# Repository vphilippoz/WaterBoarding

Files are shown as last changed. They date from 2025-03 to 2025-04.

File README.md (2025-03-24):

# WaterBoarding

This project is under developpment.

When uploaded to an ESP32, this code allows any user to toggle a water pump from a web interface. The ESP32 hosts a web page such that any device on the same network can interract with it.

## Requirements

### Arduino IDE

1. Install the esp32 board support by Espressif Systems
1. Select Tools > USB CDC On Boot > Enabled from the Arduino IDE menus (required to make Serial.print work on ESP32 boards)

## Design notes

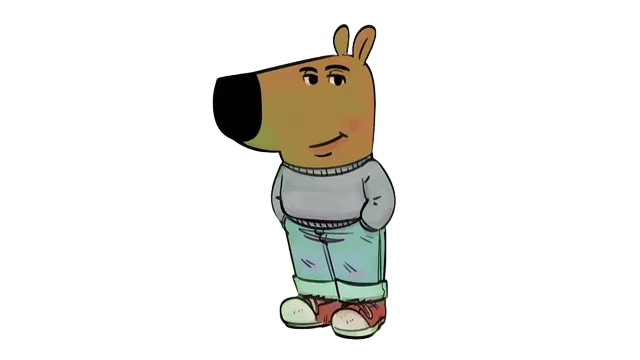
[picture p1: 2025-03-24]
PCB/chill-guy-meme-transparent.png

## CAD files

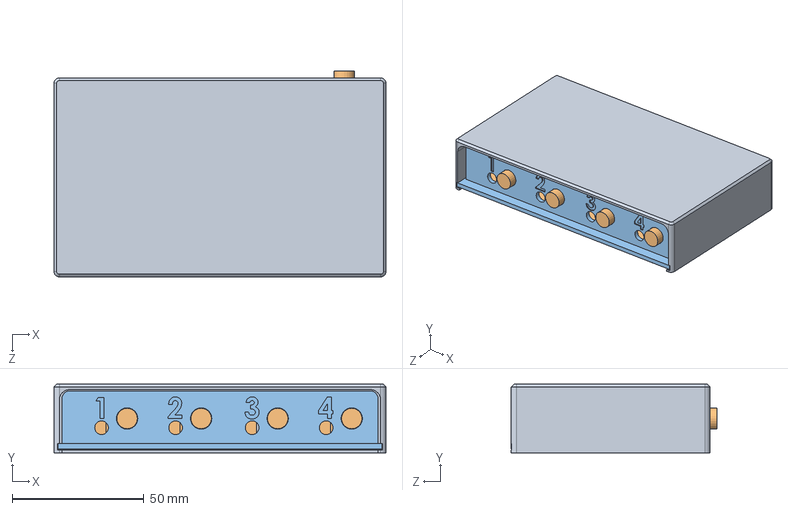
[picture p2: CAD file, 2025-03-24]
3D/asm.SLDASM
126.0 x 26.0 x 78.1 mm
pcb
bas
haut

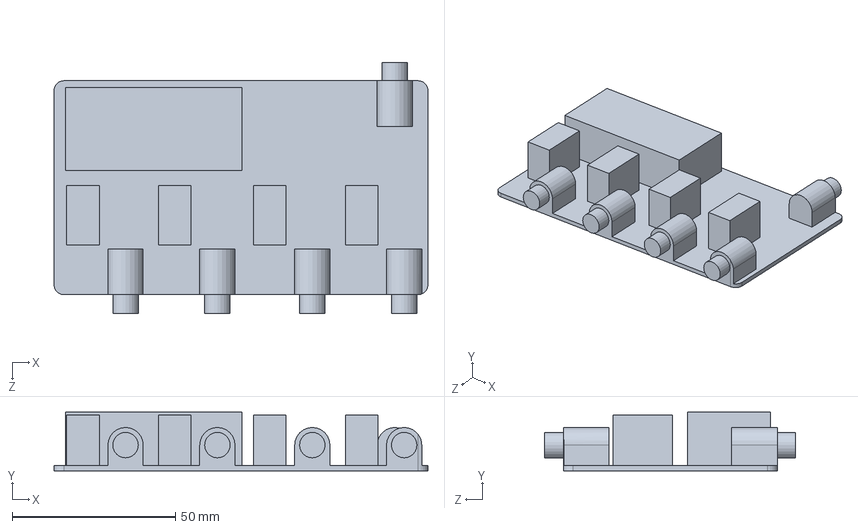
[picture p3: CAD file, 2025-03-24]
3D/pcb.SLDPRT
114.4 x 18.0 x 76.8 mm

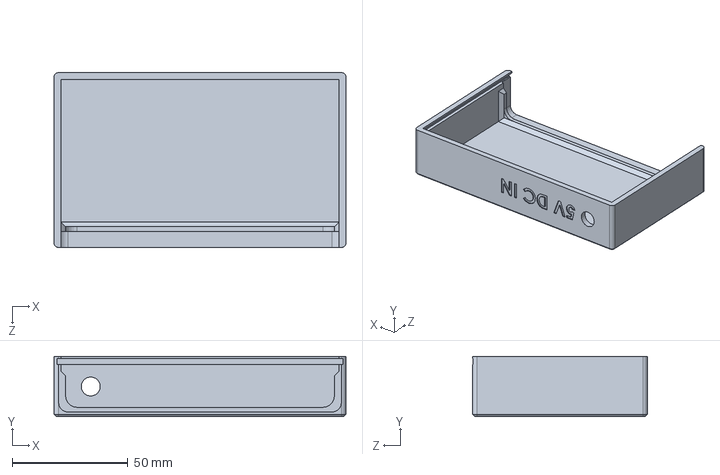
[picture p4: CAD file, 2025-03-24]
3D/haut.SLDPRT
126.0 x 26.0 x 75.5 mm

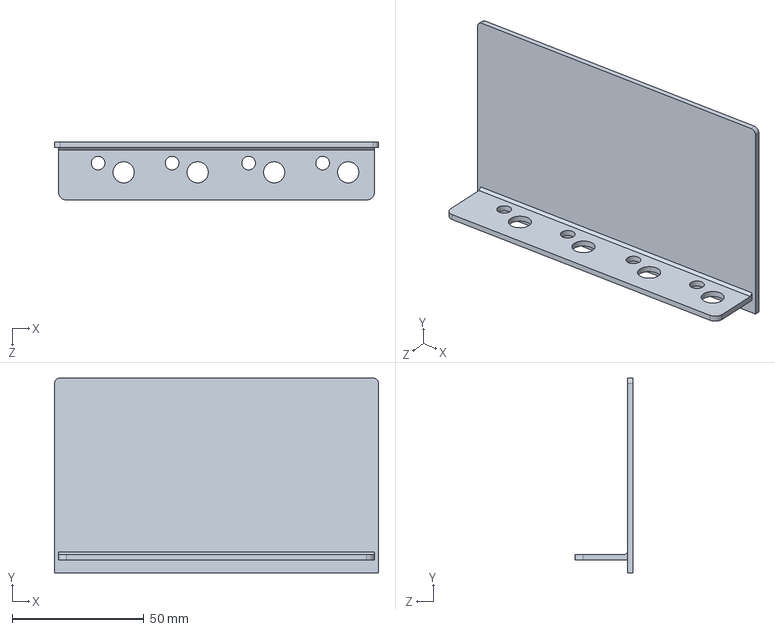
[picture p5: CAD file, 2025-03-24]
3D/bas.SLDPRT
123.0 x 74.0 x 22.0 mm

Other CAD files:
3D/bas.3MF
3D/haut.3MF

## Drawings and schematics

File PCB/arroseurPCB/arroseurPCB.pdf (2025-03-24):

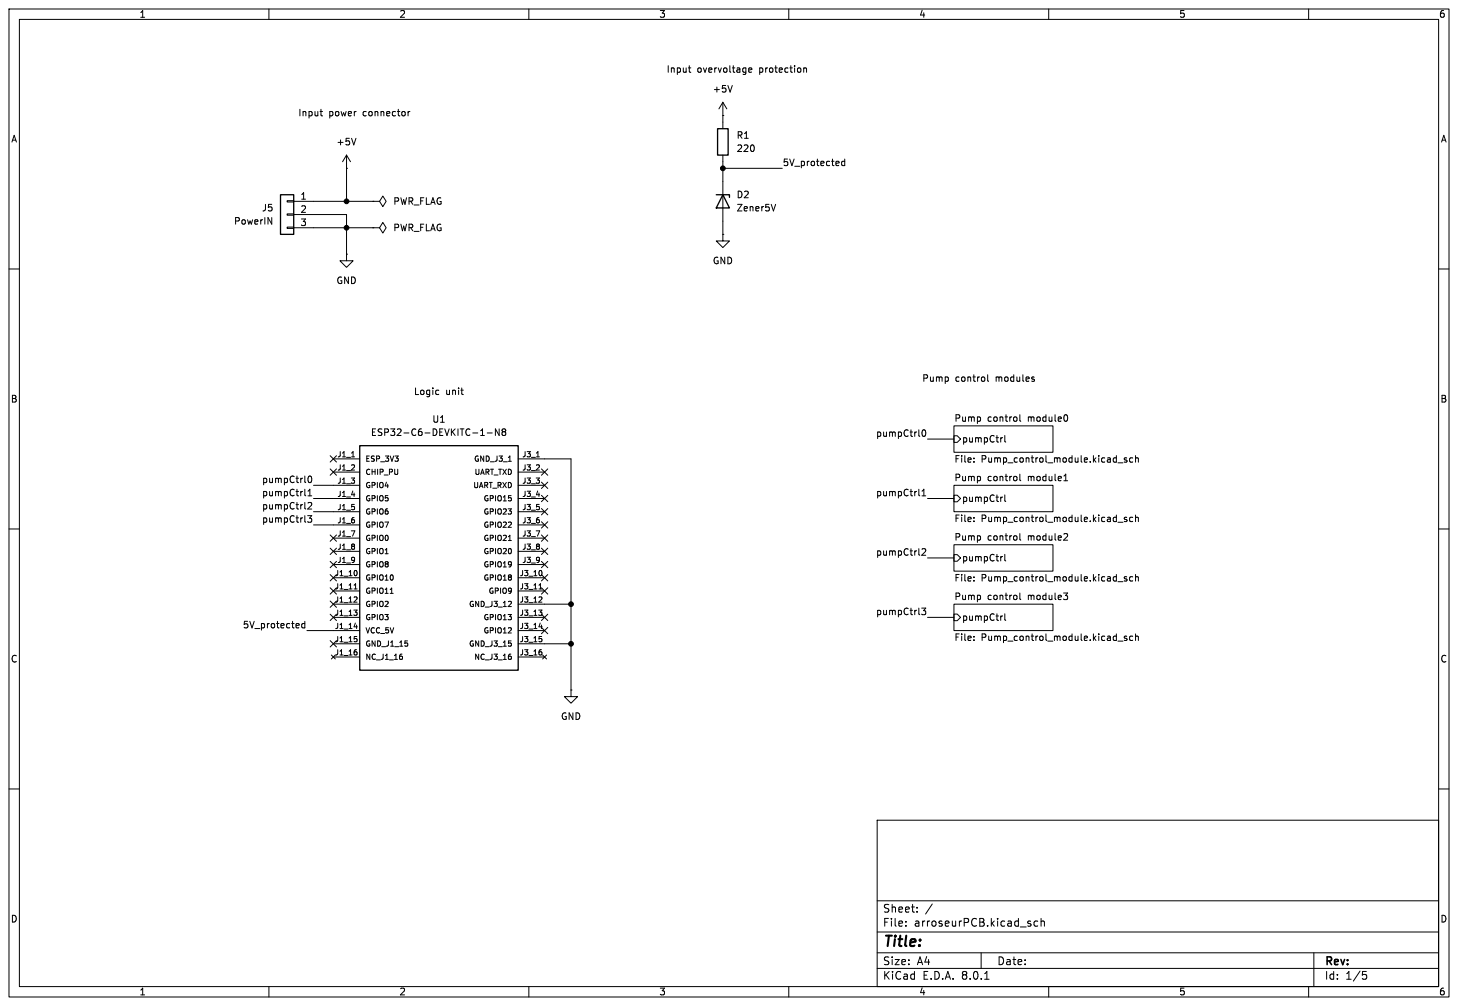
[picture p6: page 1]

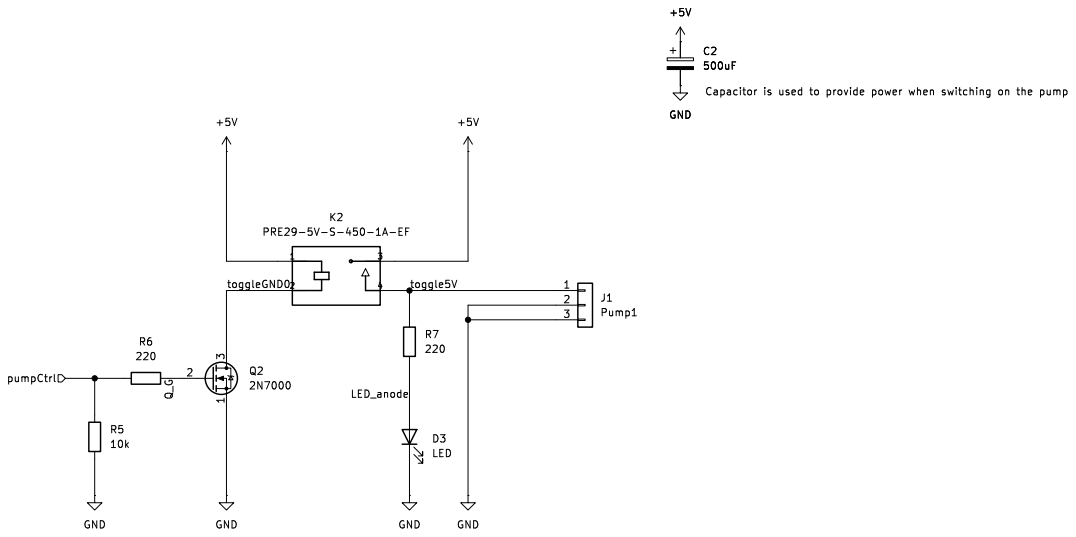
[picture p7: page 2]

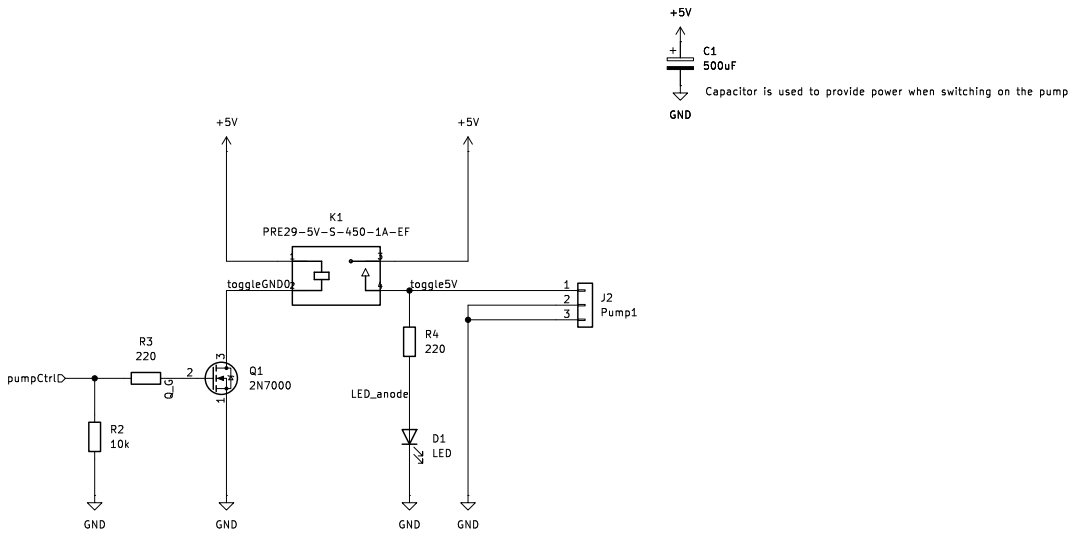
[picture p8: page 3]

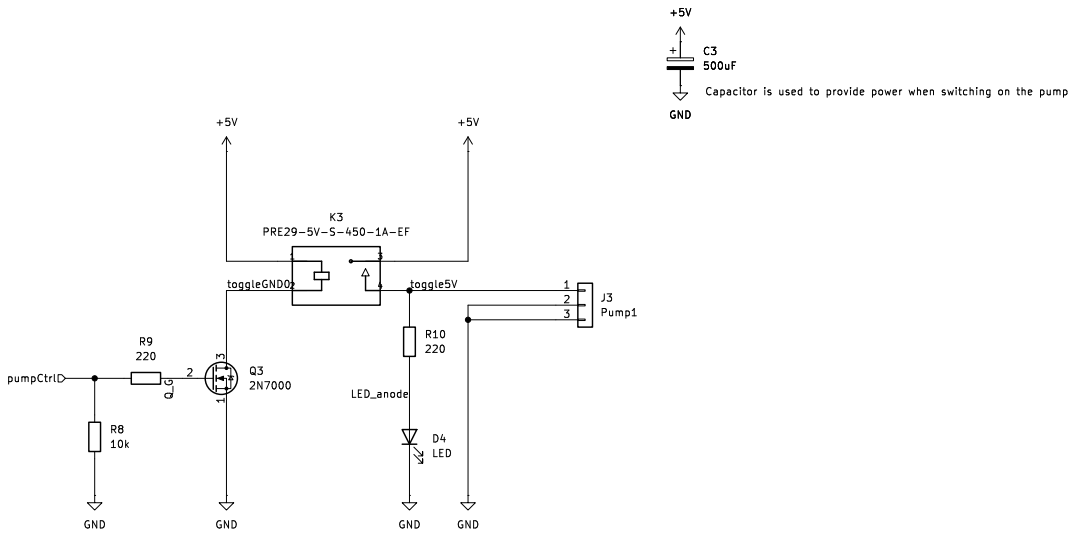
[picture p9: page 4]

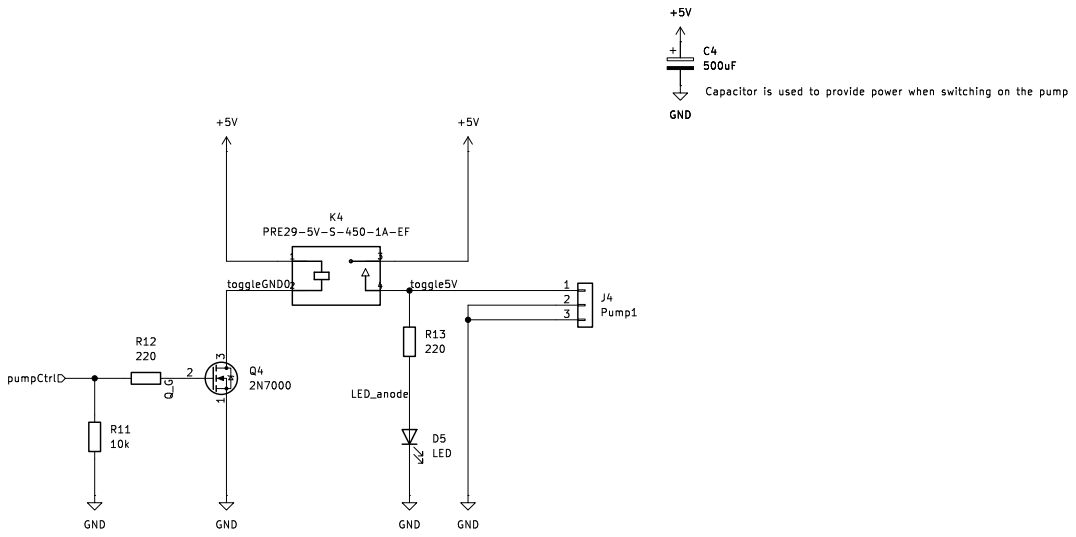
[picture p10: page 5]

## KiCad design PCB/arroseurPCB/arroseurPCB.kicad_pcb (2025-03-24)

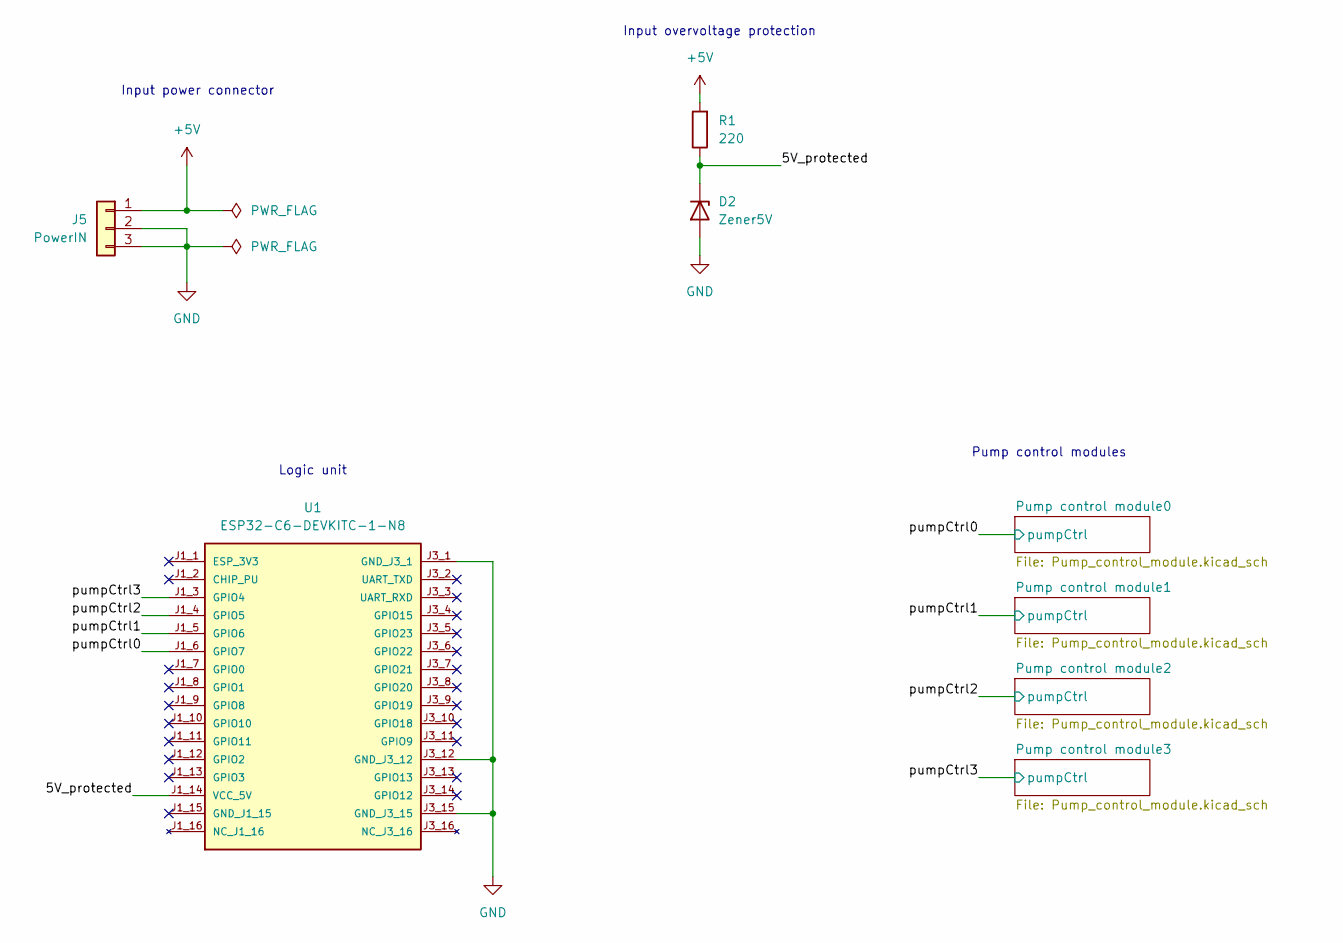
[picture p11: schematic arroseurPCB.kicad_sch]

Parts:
D2: Zener5V; D_DO-41_SOD81_P7.62mm_Horizontal
J5: PowerIN; PJ-112AH
R1: 220; R_Axial_DIN0309_L9.0mm_D3.2mm_P15.24mm_Horizontal
U1: ESP32-C6-DEVKITC-1-N8; MODULE_ESP32-C6-DEVKITC-1-N8; PARTREV 1.3

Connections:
+5V: J5.1, R1.2; also elsewhere on the board
/5V_protected: D2.1 (K), R1.1, U1.J1_14 (VCC_5V)
/pumpCtrl0: U1.J1_6 (GPIO7); also elsewhere on the board
/pumpCtrl1: U1.J1_5 (GPIO6); also elsewhere on the board
/pumpCtrl2: U1.J1_4 (GPIO5); also elsewhere on the board
/pumpCtrl3: U1.J1_3 (GPIO4); also elsewhere on the board
GND: D2.2 (A), J5.2, J5.3, U1.J3_1 (GND_J3_1), U1.J3_12 (GND_J3_12), U1.J3_15 (GND_J3_15); also elsewhere on the board

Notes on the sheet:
Logic unit
Input power connector
Input overvoltage protection
Pump control modules

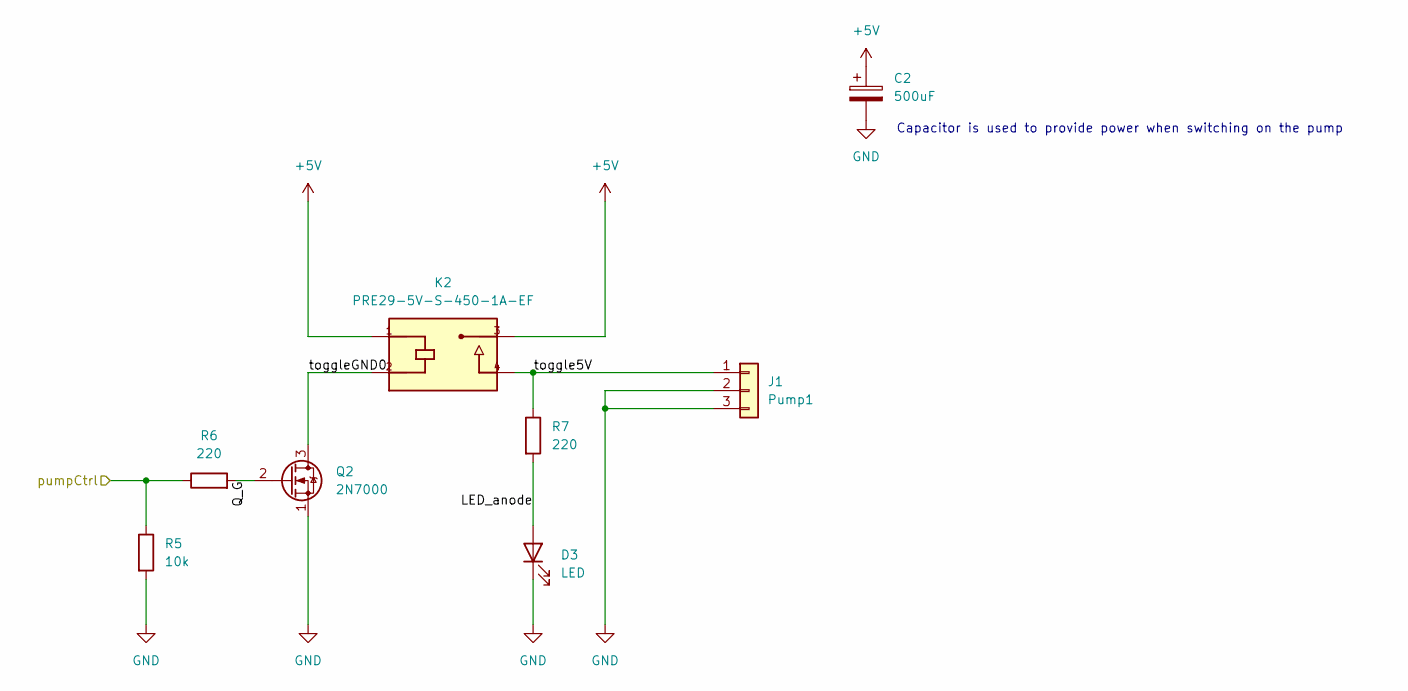
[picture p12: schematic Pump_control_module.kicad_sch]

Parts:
C2: 500uF; CP_Radial_D6.3mm_P2.50mm
D3: LED; LED_D5.0mm
J1: Pump1; PJ-112AH
K2: PRE29-5V-S-450-1A-EF; RELAY_PRE29-5V-S-450-1A-EF
Q2: 2N7000; TO-92L_HandSolder
R5: 10k; R_Axial_DIN0309_L9.0mm_D3.2mm_P15.24mm_Horizontal
R6, R7: 220; R_Axial_DIN0309_L9.0mm_D3.2mm_P15.24mm_Horizontal

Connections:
+5V: C2.1, K2.1, K2.3; also elsewhere on the board
/Pump control module0/LED_anode: D3.2 (A), R7.2
/Pump control module0/Q_G: Q2.2 (G), R6.2
/Pump control module0/toggle5V: J1.1, K2.4, R7.1
/Pump control module0/toggleGND0: K2.2, Q2.3 (D)
/pumpCtrl0: R5.1, R6.1; also elsewhere on the board
GND: C2.2, D3.1 (K), J1.2, J1.3, Q2.1 (S), R5.2; also elsewhere on the board

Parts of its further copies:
C1, C3, C4: 500uF; CP_Radial_D6.3mm_P2.50mm
D1, D4, D5: LED; LED_D5.0mm
J2: Pump1; PJ-112AH
K1, K3, K4: PRE29-5V-S-450-1A-EF; RELAY_PRE29-5V-S-450-1A-EF
Q1, Q3, Q4: 2N7000; TO-92L_HandSolder
R2, R8, R11: 10k; R_Axial_DIN0309_L9.0mm_D3.2mm_P15.24mm_Horizontal
R3, R4, R9, R10, R12, R13: 220; R_Axial_DIN0309_L9.0mm_D3.2mm_P15.24mm_Horizontal

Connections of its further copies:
+5V: C1.1, C3.1, C4.1, K1.1, K1.3, K3.1, K3.3, K4.1, K4.3; also elsewhere on the board
/Pump control module1/LED_anode: D1.2 (A), R4.2
/Pump control module1/Q_G: Q1.2 (G), R3.2
/Pump control module1/toggle5V: J2.1, K1.4, R4.1
/Pump control module1/toggleGND0: K1.2, Q1.3 (D)
/Pump control module2/LED_anode: D4.2 (A), R10.2
/Pump control module2/Q_G: Q3.2 (G), R9.2
/Pump control module2/toggle5V: K3.4, R10.1; also elsewhere on the board
/Pump control module2/toggleGND0: K3.2, Q3.3 (D)
/Pump control module3/LED_anode: D5.2 (A), R13.2
/Pump control module3/Q_G: Q4.2 (G), R12.2
/Pump control module3/toggle5V: K4.4, R13.1; also elsewhere on the board
/Pump control module3/toggleGND0: K4.2, Q4.3 (D)
/pumpCtrl1: R2.1, R3.1; also elsewhere on the board
/pumpCtrl2: R8.1, R9.1; also elsewhere on the board
/pumpCtrl3: R11.1, R12.1; also elsewhere on the board
GND: C1.2, C3.2, C4.2, D1.1 (K), D4.1 (K), D5.1 (K), J2.2, J2.3, Q1.1 (S), Q3.1 (S), Q4.1 (S), R2.2, R8.2, R11.2; also elsewhere on the board

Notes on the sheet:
Capacitor is used to provide power when switching on the pump

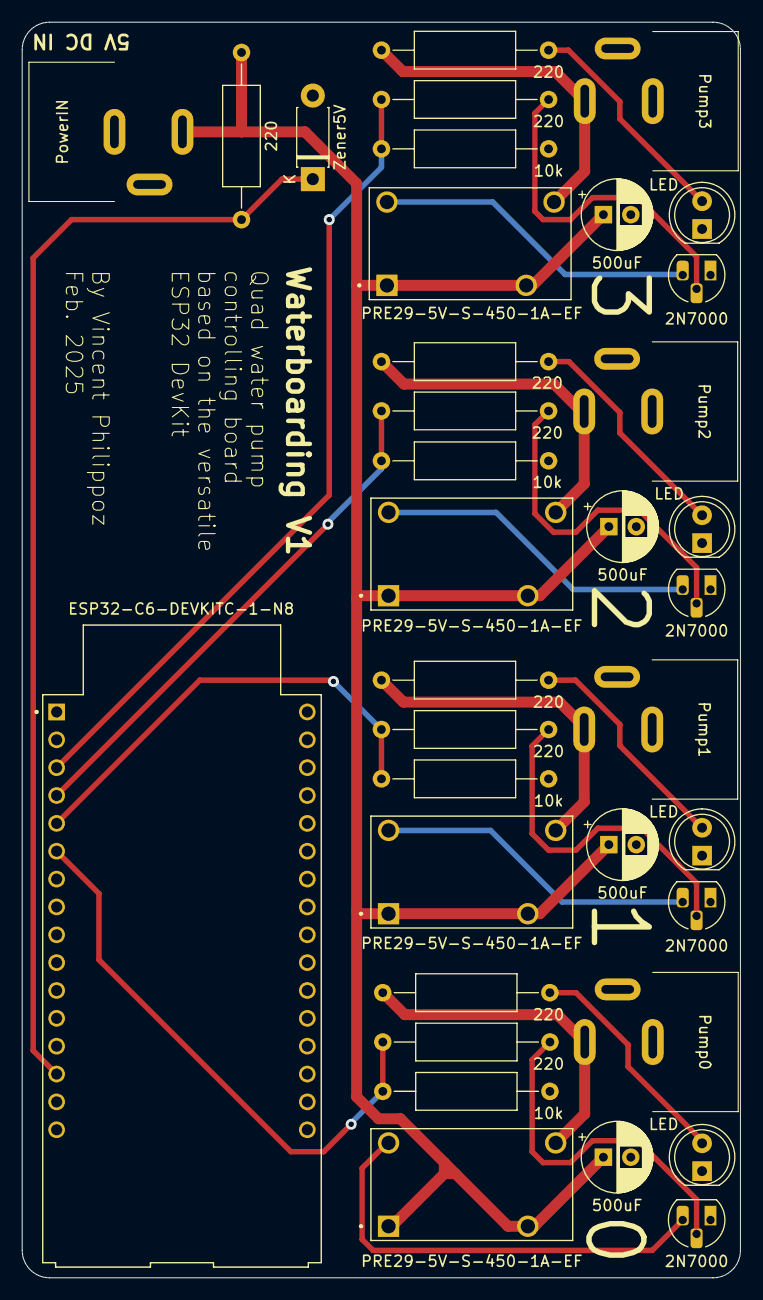
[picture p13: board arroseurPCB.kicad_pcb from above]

Board: 2 copper layers, 65.5 x 114.5 mm, 36 parts (0 on the bottom side), 23 nets.

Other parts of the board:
J3: Pump2; PJ-112AH
J4: Pump3; PJ-112AH

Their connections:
/Pump control module2/toggle5V: J3.1; also elsewhere on the board
/Pump control module3/toggle5V: J4.1; also elsewhere on the board
GND: J3.2, J3.3, J4.2, J4.3; also elsewhere on the board

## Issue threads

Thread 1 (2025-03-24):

Create clean framework

vphilippoz, 2025-03-24:
# Problem

The current codebase is a single .ino file without clear structure. Backend and frontend are mixed.

# Solution

A modular approach must be applied. Backend and frontend should be separated in different source files for greater flexibility and readability.

vphilippoz, 2025-03-27:
Resolved at commit 8648e07

Closed 2025-03-27.

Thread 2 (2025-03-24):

Onboard RGB LED as debugger

vphilippoz, 2025-03-24:
# Problem

When testing the code on the ESP32, one must either use a multimeter or serial communication to know what happens. This prevents easy testing and is not cool.

# Solution

Create a basic function that associates a color to each toggled GPIO. Thus, one can simply look at the board to see if and which GPIO is toggled.

vphilippoz, 2025-03-28:
Partially solved at release v1.0 but only one color is visible, so if two GPIOs are toggled only the last one is visible.

vphilippoz, 2025-03-28:
Issue solved by PR #5

Closed 2025-03-28.

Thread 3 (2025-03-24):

UI improvement

vphilippoz, 2025-03-24:
# Problem

The current web page is very basic and ugly.

# Solution

Make the web page more user friendly by using buttons, colors and text.

vphilippoz, 2025-04-07:
Solved with PR #6

Closed 2025-04-07.

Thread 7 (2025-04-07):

Water quantity control

vphilippoz, 2025-04-07:
# Problem

The current application only allows the user to toggle pumps. It is difficult to deliver a precise amount of water to a plant.

# Solution

Calibrate the water delivery (measure water flux) and adapt UI to deliver a requested quantity (for example, a slider with a "deliver now" button)

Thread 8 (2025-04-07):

Automated plan

vphilippoz, 2025-04-07:
# Problem

The watering system is not autonomous. A user is needed to toggle pumps.

# Solution

Create a watering schedule. At given times of the day, on given days of the week, the watering system activates autonomously. Schedule is either hardcoded (easy ugly) or setup on the web application (nice difficult).

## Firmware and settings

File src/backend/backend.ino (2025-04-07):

/*
Minimal version to test the backend library.

This code is a minimal version to test the backend library. It toggles the defined GPIOs and the corresponding LED color.
*/

#include "backend.hpp"

// Constants
constexpr unsigned int SERIAL_BAUD_RATE = 115200;
constexpr bool DEBUG = false;

void setup() {
    if(DEBUG) {
        // Open serial communications on the native USB port
        Serial.begin(SERIAL_BAUD_RATE);while(!Serial);
    }

    // Setup the library
    backend::setup(DEBUG);
    if(DEBUG) {Serial.println("Setup complete");}
}

void loop() {
    // // Toggle individually each pump
    // for(unsigned int i = 0; i < backend::NUM_PUMPS; i++) {
    //     backend::toggle_pump(i);
    //     delay(300);
    //     backend::toggle_pump(i);
    //     delay(100);
    // }

    // delay(1000);

    // // Toggle all pumps
    // for(unsigned int i = 0; i < backend::NUM_PUMPS*2; i++) {
    //     backend::toggle_pump(i%backend::NUM_PUMPS);
    //     delay(200);
    // }

    // Deliver 1 L on each pump
    for(unsigned int i = 0; i < backend::NUM_PUMPS; i++) {
        backend::deliver_ml(i, 1000);
        delay(200);
    }

    delay(1000);
}

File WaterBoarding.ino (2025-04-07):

/*
  WaterBoarding.ino - Example code for the Water Boarding project.
  Created by Vincent Philippoz.

  This code is made for the ESP32-C6 platform and is intended to be used with the Water Boarding PCB.
*/

#include "src\web_interface\web_interface.hpp"
#include "src\backend\backend.hpp"

// Constants
constexpr unsigned int SERIAL_BAUD_RATE = 115200;
constexpr bool DEBUG = true;

void setup() {
    if(DEBUG) {
      // Initialize serial communication
        Serial.begin(SERIAL_BAUD_RATE);
    }

    backend::setup(DEBUG);
    web_interface::setup(backend::toggle_pump, backend::NUM_PUMPS, DEBUG);
}

void loop() {
    // Handle client requests
    web_interface::server.handleClient();
}

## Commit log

2025-03-24 Include PCB and 3D files
    [Pump_control_module.kicad_sch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]
2025-03-25 Created working backend module (without LED)
2025-03-28 Working LED indicator (only last toggled visible)
2025-03-28 LED unique color for any pump state
2025-03-31 Set and reset pump func added
    [backend.cpp, backend.hpp]
2025-04-02 WORKS ON PCB ! (+ VERBOSE flag codewide)
2025-04-04 4 centered buttons
2025-04-04 Variable color & text on button for state feedback
2025-04-07 Pump index corection
